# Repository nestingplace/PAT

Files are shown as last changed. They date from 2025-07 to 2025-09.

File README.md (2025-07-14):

# PAT — Portable Audio Tool (Sampler/Sequencer/Synth)

<p align="center">
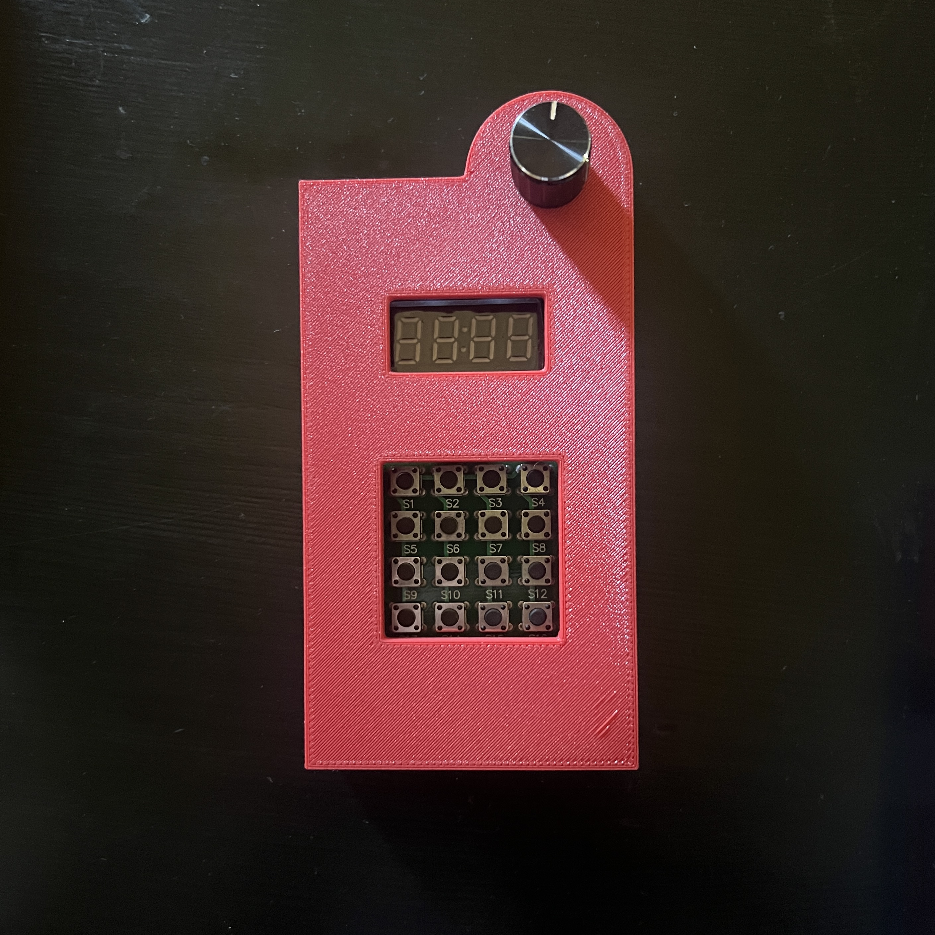
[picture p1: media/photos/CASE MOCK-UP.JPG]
Case Mock-Up
  
</p>

A standalone, hardware-based sampler and digital synthesizer built around the RP2040 microcontroller. Designed for real-time musical performance and DIY audio exploration. Developed in MicroPython, with integrated analog effects and a full sequencer UI.

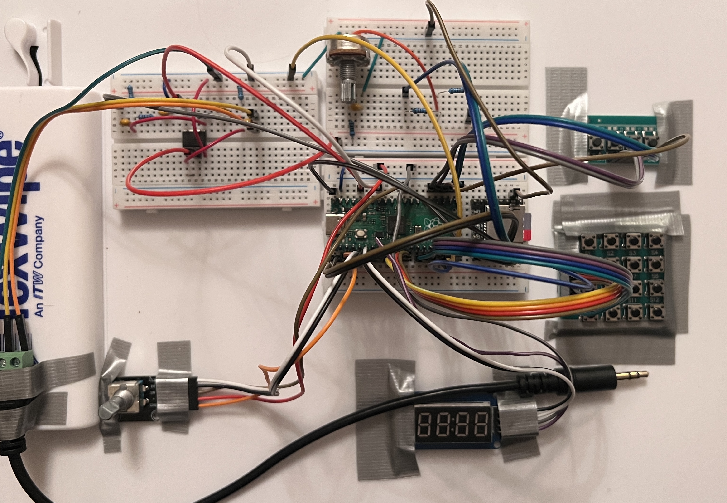
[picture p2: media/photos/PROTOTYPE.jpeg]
PAT Breadboard


# Features

- Sample playback with 16 step ( 8x2 ) grid sequencer and visualizer ( DFR0229 )
- Digital synth engine ( DDS-based ) with triangle, saw, square, and sine waveforms
- PWM audio output with ( RC ) bandpass filtering
- Encoder-based control of waveform, envelope, and FX parameters
- Transistor-based analog tremolo ( LFO modulated )
- Mode-switchable SYNTH / SAMPLE engine with combined audio out ( active summing )
- Midi & sync output support via 3.5mm TRS ( type-B )
- Open-source firmware, hardware, and enclosure design
- 2 keypads, 20 buttons ( 16 for note/sample playback, 4 for UI )
- Encoder knob for menu navigation and SYNTH control modes
- 7-segment display with fully populated menu and visual queues
- 3D printed case, fully assembled with snap-fit standoffs

# Folder Overview

- `/firmware`: MICROPYTHON CODEBASE
- `/hardware`: CIRCUIT DIAGRAMS, 3D MODELS, ETC.
- `/media`: PHOTOS & VIDEOS
- `/docs`: PRINTABLE DATASHEETS

# Technical Highlights

- Real-time waveform synthesis via PWM and timer interrupts
- Synth control modes: CUTOFF, FADE-IN, ASDR ENV, FILTER SWEEP, FILTER MOD, and PITCH BEND
- Modular state machine controlling input, output, and mode logic
- Minimal latency sampling engine using UART protocol and <asyncio>
- Playback speeds of 60-140 bpm ( 16th notes, max of 560 steps per minute )
- Threaded synth logic for DUAL MODE, SYNTH and SEQUENCER combined operation
- Permanent storage of program configuration and sequencer patterns
- Import custom sample banks via micro SD card ( MP3 and WAV )
- Fully documented hardware stack for easy replication

# Demo

SYNC W/ KORG VOLCA

SYNC : KORG VOLCA (https://youtu.be/XOAL12_DOX0)

SYNTH CONTROL 1

SYNTH CONTROL 1 (https://www.youtube.com/shorts/shXTFsdpJ9k)

SYNTH CONTROL 2

SYNTH CONTORL 2 (https://www.youtube.com/shorts/4oDAa_RGoyw)

# Work in Progress

- SYNTH melody sequencing, by step-based assignment of both rhythmic and melodic values
- Communication of SYNTH sequence values (beat & note) via MIDI-OUT signal
- Analog FX builds : DISTORTION, REVERB, DELAY

---

# Creator

Ken Hill – Embedded Engineer , [somuchfunwithwords@gmail.com](mailto:somuchfunwithwords@gmail.com)

[View my portfolio](https://drive.google.com/drive/folders/13Q4Rg4acVu6Zbi14zaWPo625oAb1vngg?usp=drive_link) | [LinkedIn](https://www.linkedin.com/in/ken-hill-5a03b9225)

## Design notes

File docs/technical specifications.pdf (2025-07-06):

STORAGE
ON-BOARD
DRIVERS | 40 KB
BUILD | 8.0 KB
TOTAL | 2 MB

SDHC MICRO SD CARD
64 x MP3 | ≈ 8 MB
TOTAL | 32 GB

POWER BUDGET
RPi PICO | - 100mA
TM1637 DISPLAY | - 80mA
4X4 KEYPAD | - 5mA
KY040 ENCODER | - 15mA
AUDIO MODULE | - 300mA
TP2399 DELAY | - 30mA
LM358 OP-AMP | - 20mA
PT2399 DELAY | - 30mA
LI-PO BATTERY | + 10000mAh + 5000mAh + 2500mAh
TOTAL | 10000mAh / 525mA _________ 19.05h
| 5000mAh / 525mA _________ 9.53h
| 2500mAh / 525mA _________ 4.76h

# technical specifications

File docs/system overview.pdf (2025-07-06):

### I. HARDWARE

CURRENT HARDWARE

RPi Pico Main microcontroller (PWM + GPIO management) DFR0229 MP3 audio playback module (sampler)
TM1637 Display 4-digit 7-segment for menu and sequence UI KY040 Encoder Navigation knob with rotation and button
4x4 Keypad Primary input matrix (samples, controls)
3.5mm TRS Port 1 Main audio output (stereo or mono blend) 3.5mm TRS Port 2 MIDI OUT or SYNC OUT toggleable
LP Filter Bandpass filter for PWM synth (23.4 Hz–7.2 kHz) LM358 Op-amp for signal buffering and blending

### II. SOFTWARE ARCHITECTURE

LANGUAGE & OPERATING SYSTEM

MicroPython (Async + Threading)

Event-driven architecture, with I/O polling via coroutines and background threading for concurrent synth playback

### III. PROGRAM LOGIC

PROGRAMS AND DATA STRUCTURES

### 4 user-selectable "Programs" (P1–P4)

Each program saves to its own .json config file

Program data includes:

BPM
Waveform
Synth Control Mode
Sequence Pattern
MIDI/SYNC Mode

Samples are stored and triggered according to DFR0229 folder/file scheme (folder = program number, file = keypad index)

### IV. FUNCTIONAL MODES

### 1. SAMPLER MODE

# system overview

– Direct triggering of samples via keypad – Uses DFPlayer async protocol – Supports 16 samples (mapped 1–16 on 4x4 matrix) – Output is stereo or mono (merged via analog blend)

2. SEQUENCER MODE – 16-step pattern sequencer with live visual display (TM1637) – Encoder selects step; keypad assigns sample

Control buttons: - START/STOP

- DELETE STEP
- CLEAR PATTERN
- TOGGLE DUAL MODE –

– Pattern auto-saves and auto-loads per program
BPM affects: - Sample timing
- MIDI Clock or SYNC pulse (selected via CONFIGURE) –

– Sequence runs asynchronously, with idle visual feedback when stopped

3. SYNTHESIZER MODE – Monophonic DDS-style digital synth via PWM (GPIO15) – Waveforms: SIN, TRI, SAW, SQR (generated via 256-point lookup tables) – Keypad maps to C3–C4 notes

Encoder adjusts real-time modulation target: - DISABLED

- CUTOFF
- ASDR
- FILTER MOD
- FILTER SWEEP
- PITCH BEND

–

– Synth playback uses background threading – Static bandpass filter applied post-PWM

– Output merged via op-amp circuit with DFR0229 stream

### 4. CONFIGURATION MENU

Accessible per program, with options: – BPM: Set tempo (60–140 BPM) – WAVE: Select default waveform for synth – CTRL: Assign encoder's control mode in synth

MIDI / SYNC: - Mutually exclusive
- Determines output type on TRS Port 2 – V. I/O & DISPLAY INTERFACE
Input | Description
Encoder | Navigation + value editing

Encoder SW | Select / Back
Keypad | Note/sample trigger & sequence edit
Output | Description
TM1637 Display | 4-char mode/status & sequence grid
TRS Port 1 | Stereo or mono audio out
TRS Port 2 | MIDI or SYNC signal out

### VI. ADVANCED FEATURES

Live pattern recording:
Sample assignment while sequence runs

Async + threading:
Asyncio for playback/scheduler loop
Thread for continuous synth tone generation

Dual mode:
Allows for concurrent synth/sequencer operaiton

Power system:
USB-C charging via TP4056
Rechargeable Li-Po battery

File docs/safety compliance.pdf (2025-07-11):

Document Version: 1.0
Project: Sampler / Sequencer / Synthesizer Date: [07/11/2025]

## Electrical Safety

Device operates at low voltages (≤5V DC).
Supply voltages:
Raspberry Pi Pico: 1.8–5.5V (VSYS), 3.3V logic DFPlayer Mini: 3.2–5V supply, 3.3–5V logic Always use a regulated, fused 5V supply.
Protect against reverse polarity and short circuits.

## Thermal Safety

No significant heat generation expected.
Ambient operating temperature: 0–50°C recommended. Provide basic airflow to avoid heat buildup.

## Mechanical Safety

Enclosure must have smooth edges, secure mounting. Use PCB standoffs; avoid stressing connectors. External ports (TRS, power) must be strain-relieved.

## EMI & ESD

Ground metal parts to reduce ESD risk.
Keep digital signal lines away from audio paths.
Use shielded cables where possible.

## MIDI & SYNC Output

MIDI OUT conforms to MIDI 1.0 electrical spec (31250 baud, 5V). TRS Type B wiring:
Tip → UART TX via 220Ω
Ring → GND
Sleeve → GND
SYNC OUT: 0–5V square wave, 16 pulses per quarter note.

## Software Safety

Debounce all mechanical inputs.
Ensure all GPIOs are set to known states at power-on. Provide “STOP” mode to silence audio and reset safely.

## Compliance Guidance

This project is DIY and not certified; however, design aligns with: CE / FCC Part 15 Class B (EMC)
RoHS (lead-free solder, compliant components)
WEEE (recyclable materials recommended)

# safety compliance

## Component Notes

Component | Notes
Raspberry Pi Pico | CE, FCC, RoHS certified development board.
DFPlayer Mini (DFR0229) Ensure clean 3.2–5V rail for noise-free audio.
TM1637 Display | 3.3–5V tolerant.
KY-040 Encoder | Mechanical bounce — debounce required.
Custom Analog Circuits Keep within safe voltage/current limits.

## Recommended Protections

Series resistors (220–1kΩ) on all GPIO outputs.
100nF ceramic decoupling caps on supply rails.
Fuse on main power input (500mA–1A fast-blow recommended).

For internal and educational use only. Not an official certified document.

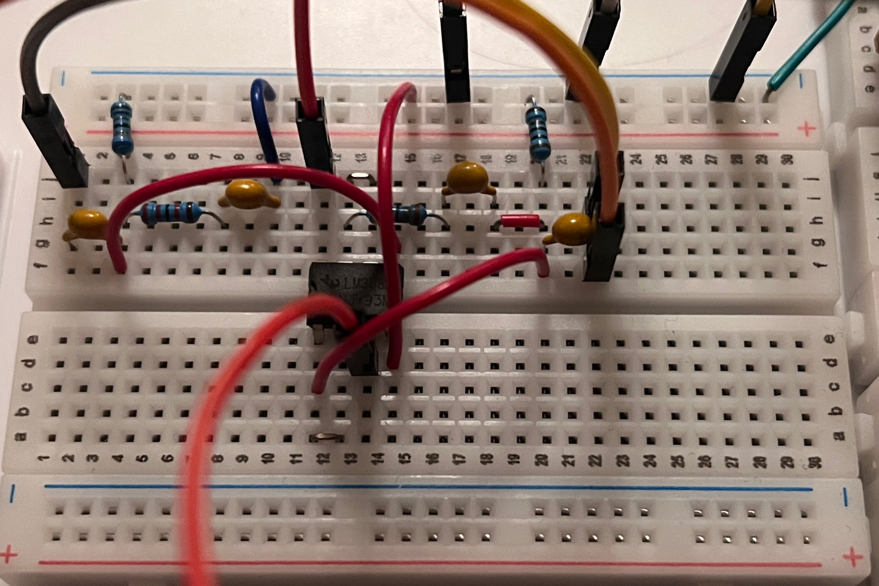
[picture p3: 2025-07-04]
media/photos/BP FILTER + AMPLIFIER.jpeg

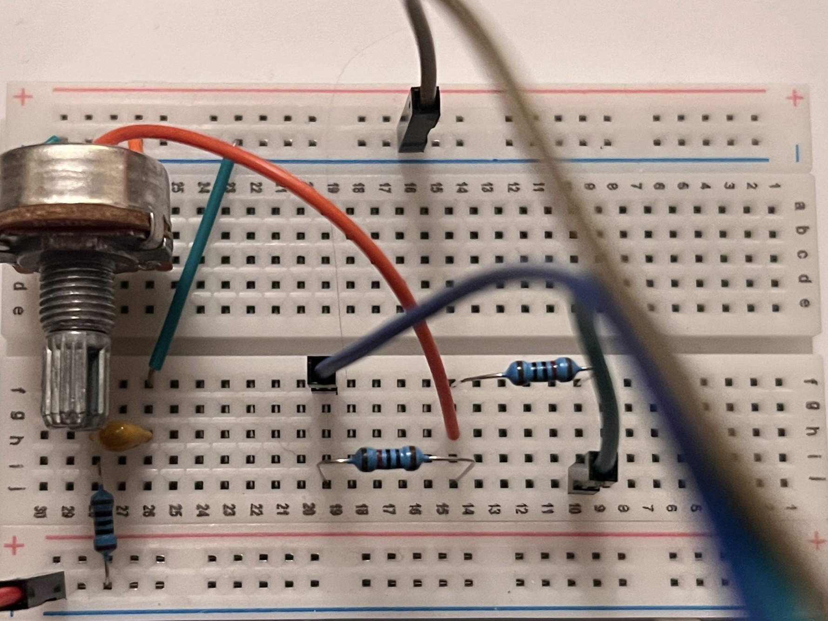
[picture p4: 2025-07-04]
media/photos/LP FILTER.jpeg

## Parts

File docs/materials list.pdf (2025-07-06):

BILL OF MATERIALS
RPi PICO BOARD | RPi PICO $1.95 OR RPi PICO 2 $5.41
TM1637 DISPLAY | $0.94-2.86
4X4 KEYPAD | $0.66-3.14
KY040 ENCODER | $1.53-4.68
POWER SUPPLY | 5 VDC MINI-PLUG AC ADAPTER $3.89 3.7V RECHARGABLE LI-PO BATTERY 10000mAh $9.47 OR 3.7V RECHARGABLE LI-PO BATTERY 5000mAh $7.49 OR 3.7V RECHARGABLE LI-PO BATTERY 2500mAh $8.16 + LITHIUM BATTERY CHARGING MODULE $0.99
AUDIO MODULE | RPi PICO AUDIO BOARD $4.91 DFR0299 $1.33 + PJ-320D 3.5MM TRS PANEL-MOUNT JACK $0.12 LM358P DUAL OP-AMP $2.35 B100K POTENTIOMETER $1.03
TOTAL MIN | $26.92
TOTAL MAX | $40.03

# materials list

OTHER COMPONENTS
5-WAY SWITCH | R16 ROTARY BAND SWITCH [SP5T] $2.89
AUDIO-FX MODULE | PT2399 BOARD $2.61-5.36
3.5MM TERMINAL | 3-PIN MALE AUDIO/VIDEO PLUG $2.61
4X1 KEYPAD | 4-PIN INPUT ARRAY $0.87
MICRO SD CARD | 32GB SDHC MICRO SD CARD $3.05-6.63

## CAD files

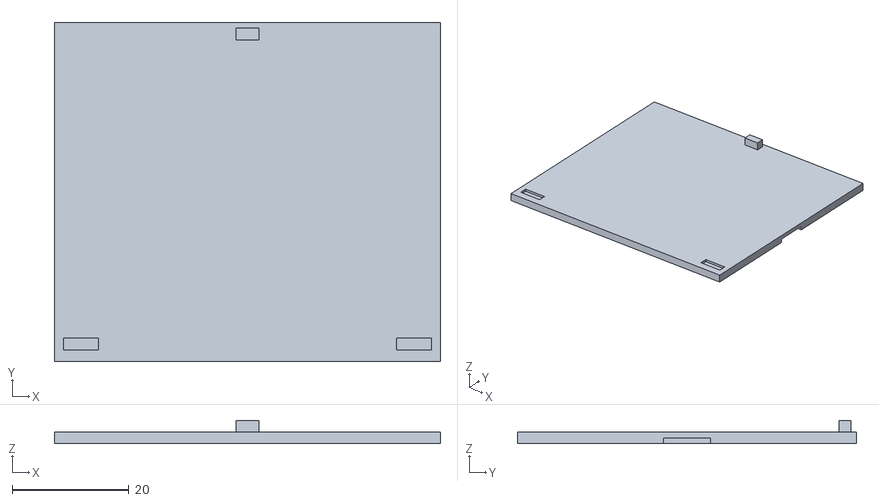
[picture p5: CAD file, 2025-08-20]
hardware/case design/STL/sequencer_case_INSERT_v1.1.stl
66.0 x 58.0 x 4.00

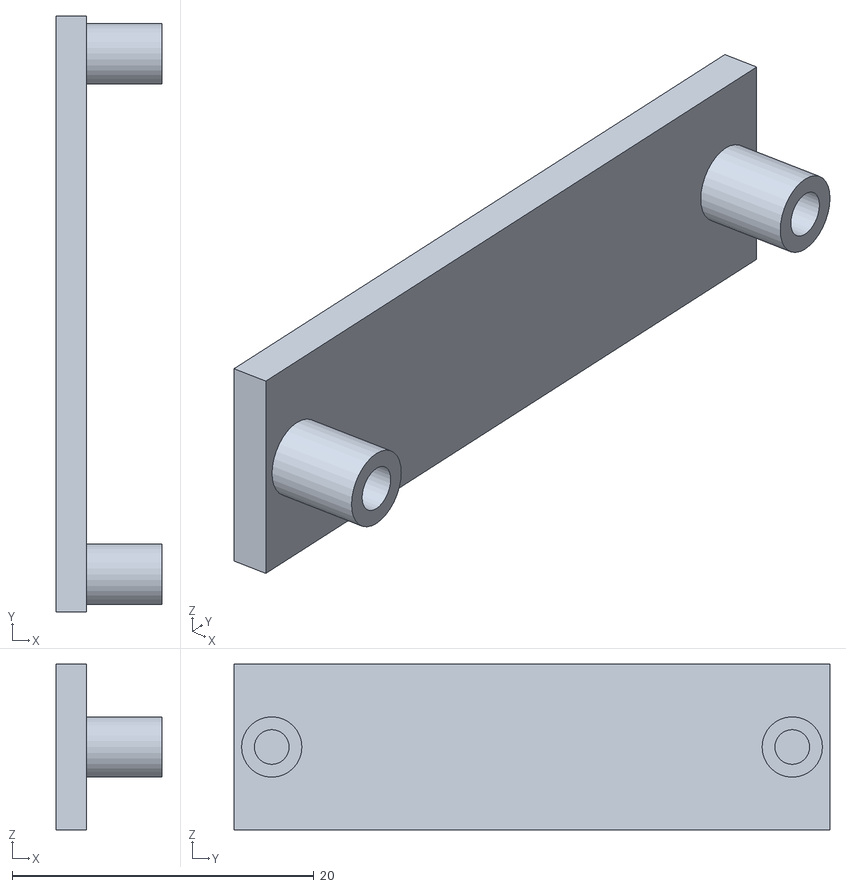
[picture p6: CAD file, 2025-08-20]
hardware/case design/STL/sequencer_case_AUDIOBOARDCLIP_v1.0.stl
7.00 x 39.5 x 11.0

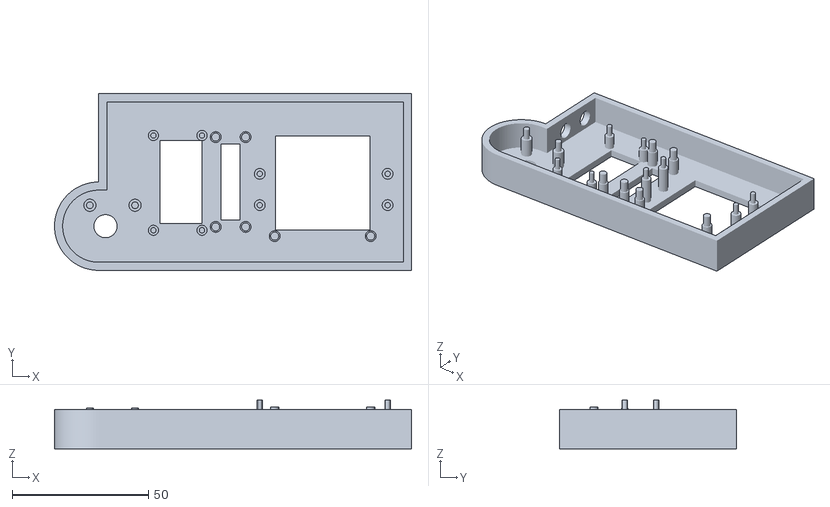
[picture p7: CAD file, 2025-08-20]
hardware/case design/STL/sequencer_case_FRONT_v2.3.stl
131.2 x 65.0 x 18.0

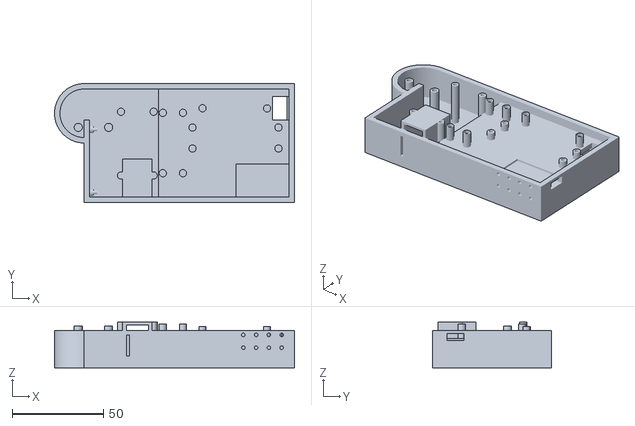
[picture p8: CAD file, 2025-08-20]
hardware/case design/STL/sequencer_case_BACK_v2.6.stl
131.2 x 65.0 x 25.0

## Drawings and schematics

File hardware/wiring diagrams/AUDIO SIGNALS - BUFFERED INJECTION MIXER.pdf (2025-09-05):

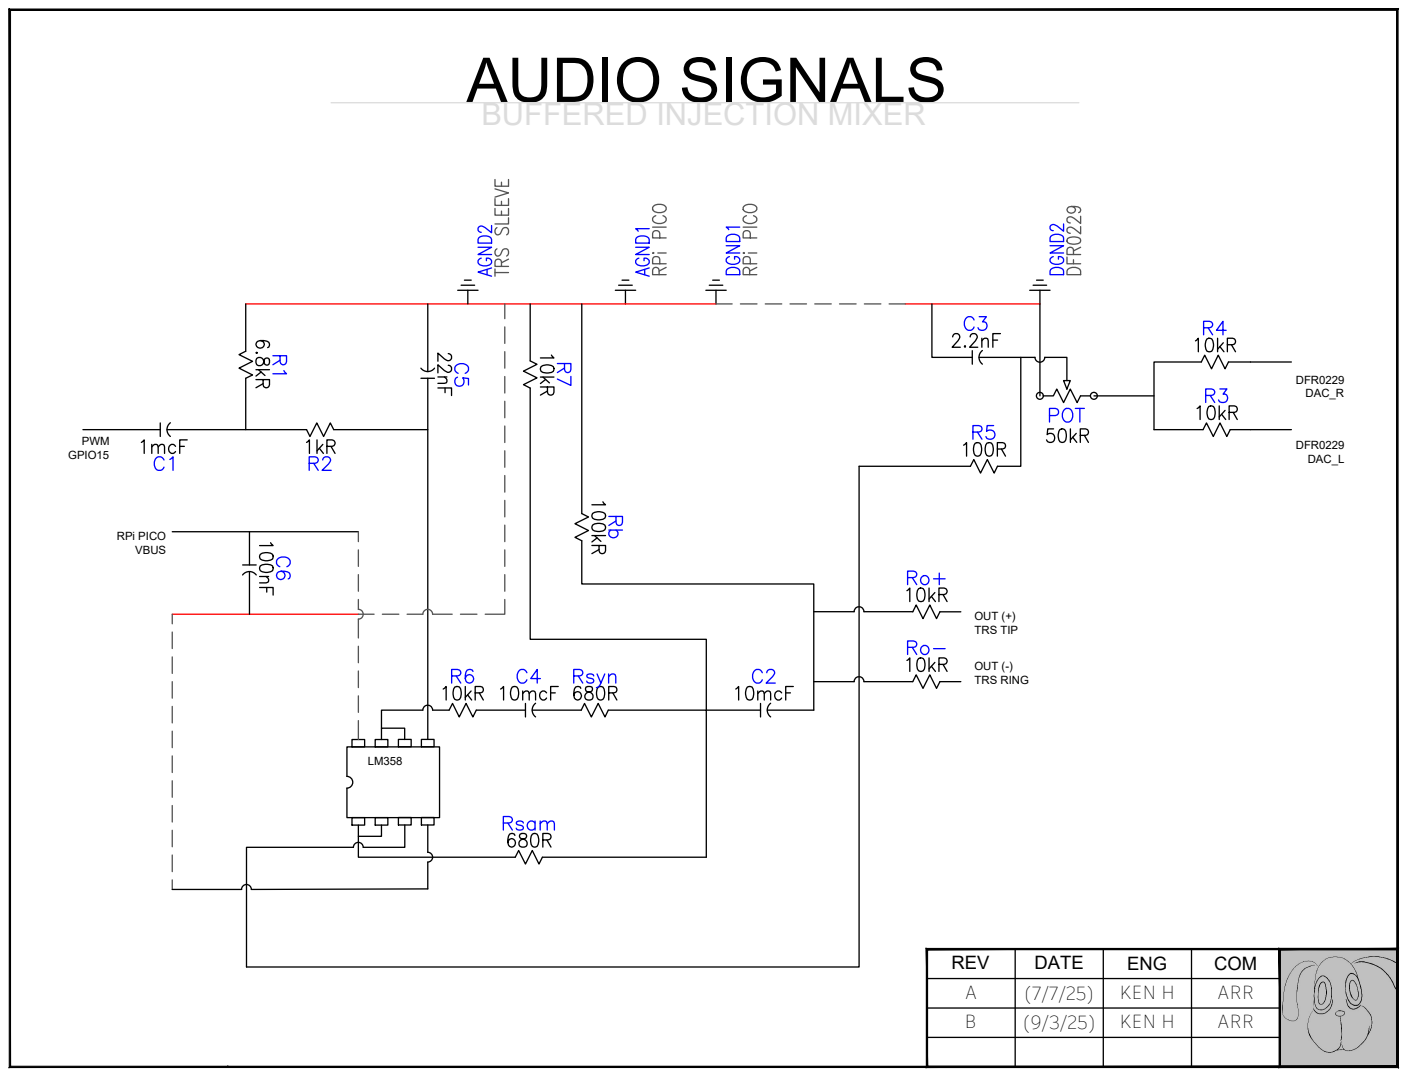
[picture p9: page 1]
AUDIO SIGNALS BUFFERED INJECTION MIXER; REV; DATE; ENG; COM A; KEN H; ARR; DFR0229 DAC_R DFR0229 DAC_L OUT (+) TRS TIP OUT (-) TRS RING RPi PICO VBUS; LM358 PWM GPIO15

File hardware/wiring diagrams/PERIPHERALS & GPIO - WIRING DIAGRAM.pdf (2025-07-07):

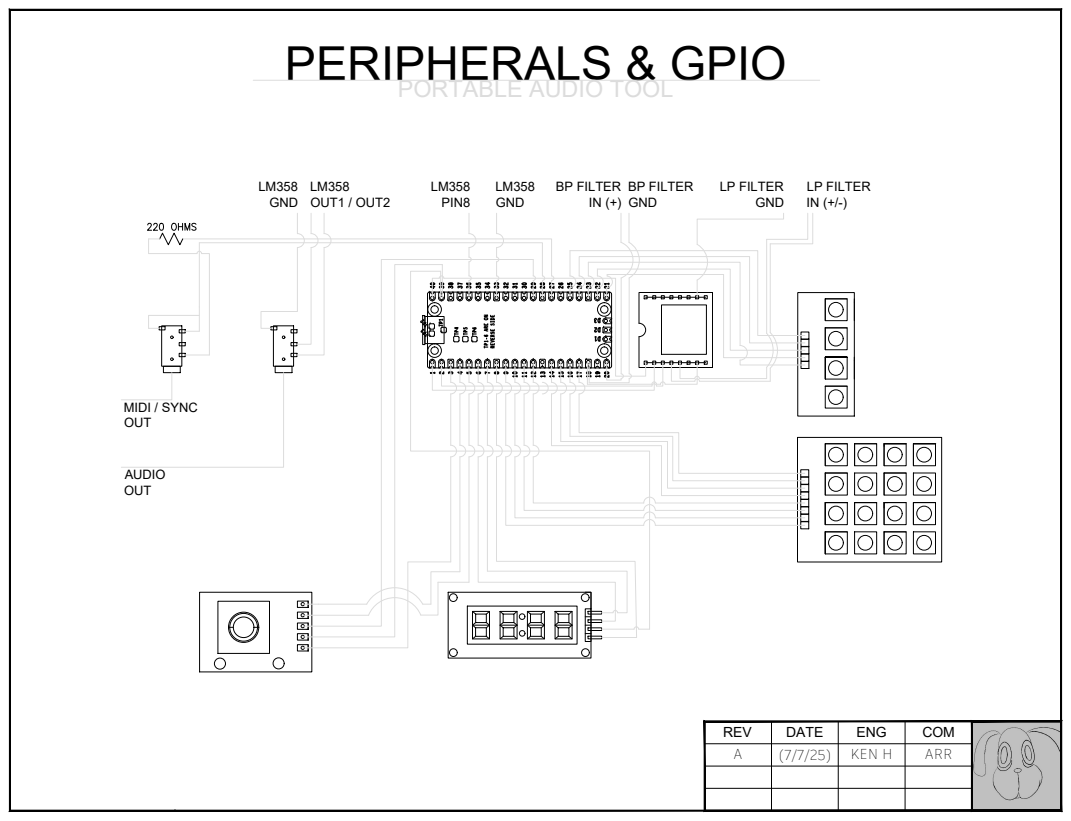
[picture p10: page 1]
LM358 PIN8; LM358 GND; BP FILTER IN (+) BP FILTER GND MIDI / SYNC OUT AUDIO OUT; LP FILTER GND; LP FILTER IN (+/-) LM358 GND LM358 OUT1 / OUT2 PERIPHERALS & GPIO PORTABLE AUDIO TOOL; REV; DATE; ENG; COM A; KEN H; ARR

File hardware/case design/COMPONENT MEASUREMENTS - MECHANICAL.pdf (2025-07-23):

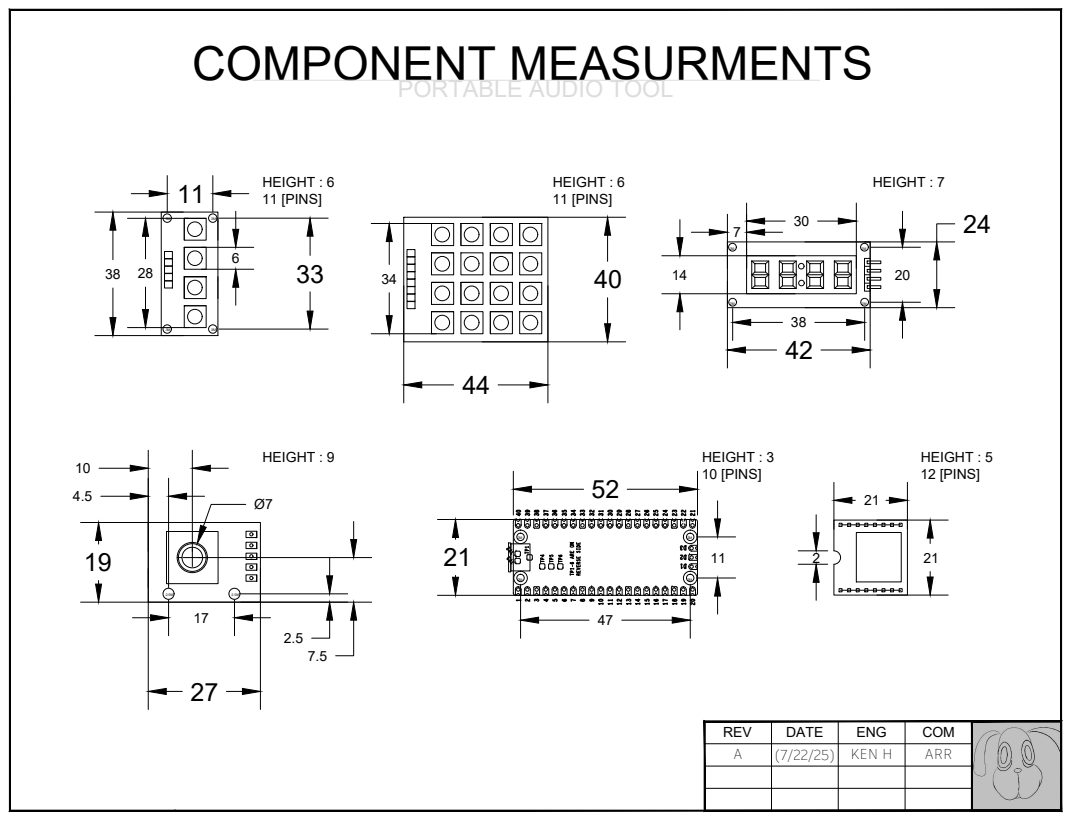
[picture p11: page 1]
REV; DATE; ENG; COM A; KEN H; ARR COMPONENT MEASURMENTS 3M; HEIGHT : 6 11 [PINS]; 40 HEIGHT : 6 11 [PINS]; HEIGHT : 7 2M; 20 HEIGHT : 9; HEIGHT : 3 10 [PINS]; HEIGHT : 5 12 [PINS] 27 19; 21 PORTABLE AUDIO TOOL

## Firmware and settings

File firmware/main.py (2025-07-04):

# STANDARD LIBRARIES
import uasyncio as asyncio
import time
import ujson
from machine import Pin, UART

# PERIPHERAL DRIVERS
from dfplayer import DFPlayer
from keypad import Keypad
from navpad import Navpad
from encoder import Encoder
from tm1637 import TM1637

# CUSTOM OBJECTS
from sequencer import Sequencer
from tremolo import TremoloController
from synthesizer import Synthesizer

# DRIVER INITIALIZATION
df = DFPlayer(uart_id=0, tx_pin_id=0, rx_pin_id=1)
df.volume(100)

midi_uart = UART(1, baudrate=31250, tx=Pin(20))

tm_display = TM1637(clk=Pin(5), dio=Pin(4))

A_ROWS = 4
A_COLS = 4
A_ROW_PINS = [13, 12, 11, 10]
A_COLUMN_PINS = [9, 8, 7, 6]
A_KEYMAP = ['1', '2', '3', 'A',
          '5', '6', '7', 'B',
          '9', '10', '11', 'C',
          '13', '14', '15', 'D']

keypad = Keypad(A_KEYMAP, A_ROW_PINS, A_COLUMN_PINS, A_ROWS, A_COLS)
keypad.set_debounce_time(200)

B_PINS = [19, 18, 17, 16]
B_KEYMAP = ['17', '18', '19', 'E']

navpad = Navpad(B_KEYMAP, B_PINS)

tremolo = TremoloController(pin_num=19, bpm=80, display=tm_display)

encoder = Encoder(2, 3, 22)

programs = ["P1", "P2", "P3", "P4"]
current_program_index = 0

# BOOT SCREEN

tm_display.scroll("Hello Hello Hello Hello")

# HANDLE PROGRAM DATA [JSON]
from program_io import load_program, save_program

def load_program(program_name):  # Legacy definition replaced
    folder_number = int(program_name[1:])
    try:
        with open(f"{program_name}.json", "r") as f:
            data = ujson.load(f)
    except:
        data = {}
    return {
        "program": program_name,
        "folder": folder_number,
        "bank":data.get("bank",1),
        "bpm": data.get("bpm", 80),
        "waveform": data.get("waveform", "SIN"),
        "control": data.get("control", "DISABLED"),
        "control_value": data.get("control_value", 0),
        "sequence": data.get("sequence", [None] * 16),
        "midi": data.get("midi", False),
        "sync": data.get("sync", False)
    }

def save_program(program_data):
    name = program_data.get("program")
    if not name:
        folder = program_data.get("folder", 1)
        name = f"P{folder}"
        program_data["program"] = name
    with open(f"{name}.json", "w") as f:
        ujson.dump(program_data, f)
        
def display_program(name):
    tm_display.show('    ')
    tm_display.show(name)

def change_bank(program_data, toggle):
    bank = program_data.get("bank", 1)
    if toggle:
        bank = 1 if bank >= 4 else bank + 1
    else:
        bank = 4 if bank <= 1 else bank - 1
    program_data["bank"] = bank
    save_program(program_data)
    
# DISPLAY MAP

def display_mode(mode):
    tm_display.show('    ')
    
    # PROGRAM SUB-MENU
    if mode == "SELECT":
        tm_display.show("SEL")
    elif mode == "SAMPLE":
        tm_display.show("SAMP")
    elif mode == "SYNTH":
        tm_display.show("SYNT")
    elif mode == "SEQ":
        tm_display.show("SEQ")
    elif mode == "CONFIGURE":
    
    # CONFIGURATION MENU
        tm_display.show("CNFG")
    elif mode == "BACK":
        tm_display.show("BACK")
    elif mode == "BPM":
        tm_display.show("BPM")
    elif mode == "WAVE":
    
    # WAVEFORMS
        tm_display.show("WAVE")
    elif mode == "SIN":
        tm_display.show("SIN")
    elif mode == "TRI":
        tm_display.show("TRI")
    elif mode == "SAW":
        tm_display.show("SAW")
    elif mode == "SQR":
        tm_display.show("SQR")
    
    # CONTROL MODES
    elif mode == "CTRL":
        tm_display.show("CTRL")
    elif mode == "DISABLED":
        tm_display.show("DSBL")
    elif mode == "CUTOFF":
        tm_display.show("CUT")
    elif mode == "ASDR":
        tm_display.show("FIN")
    elif mode == "ASDR_WAVE":
        tm_display.show("ASDR")
    elif mode == "FILTER MOD":
        tm_display.show("FMOD")
    elif mode == "FILTER SWEEP":
        tm_display.show("FSWP")
    elif mode == "PITCH BEND":
        tm_display.show("PBND")
    elif mode == "ON":
        tm_display.show("ON")
    elif mode == "OFF":
        tm_display.show("OFF")
        
    # MIDI / SYNC
    elif mode == "MIDI":
        tm_display.show("MIDI")
    elif mode == "MIDI ON":
        tm_display.show("ON")
    elif mode == "MIDI OFF":
        tm_display.show("OFF")
    elif mode == "SYNC":
        tm_display.show("SYNC")
    elif mode == "SYNC ON":
        tm_display.show("ON")
    elif mode == "SYNC OFF":
        tm_display.show("OFF")

running_program = False
sequencer_global = None  # GLOBAL SEQUENCER REFERENCE

# SYNTH MODE [PWM/THREADING]

async def synth_mode(program_data):
    display_mode("SYNTH")
    synth = Synthesizer(pwm_pin=15, program_data=program_data)

    note_map = {
        '1': 261.63, '2': 293.66, '3': 329.63, 'A': 349.23,
        '4': 392.00, '5': 440.00, '6': 493.88, 'B': 523.25,
        '7': 554.37, '8': 587.33, '9': 622.25, 'C': 659.25,
        '10': 698.46, '11': 739.99, '12': 783.99, 'D': 830.61
    }

    current_key = None
    while True:
        key = keypad.get_key()
        nav = navpad.get_key()

        if nav:
            if nav == 'E':
                synth.octave_up()
            elif nav == '19':
                synth.octave_down()
            # elif nav == '18':
            # elif nav == '17':

        if key in note_map:
            if key != current_key:
                    synth.stop_note()
                    current_key = key
                    synth.start_note(note_map[key])
        else:
            # NO KEY DETECTED, CHECKS FOR RELEASE OF MOST RECENT KEY
            if current_key and not keypad.is_pressed(current_key):
                synth.stop_note()
                current_key = None
       
        direction = encoder.get_direction()
        if direction:
            synth.update_control(direction)

        if encoder.get_button_press():
            synth.stop_note()
            return

        await asyncio.sleep_ms(10)

# SAMPLE MODE [DFPLAYER]

async def sample_mode(folder, program_data):
    global running_program
    running_program = True
    
    SAMPLE_KEYMAP = {
    '1': 1,  '2': 2,  '3': 3,  'A': 4,
    '5': 5,  '6': 6,  '7': 7,  'B': 8,
    '9': 9,  '10': 10, '11': 11, 'C': 12,
    '13': 13, '14': 14, '15': 15, 'D': 16
    }
    
    tm_display.scroll(f"B{program_data['bank']}")
    display_mode("SAMPLE")
    
    while running_program:
        
        key = keypad.get_key()
        nav = navpad.get_key()

        # KEYPAD
        if key in SAMPLE_KEYMAP:
            key_num = SAMPLE_KEYMAP[key]
            sample_offset = (program_data["bank"] - 1) * 16
            sample = key_num + sample_offset
            await df.play(folder, sample)
            
            # DEBUG
            print(f"Key {key} → Sample {sample}")

        # NAVPAD
        if nav:
            if nav == 'E':
                change_bank(program_data, toggle=True)
                tm_display.scroll(f"B{program_data['bank']}")
                display_mode("SAMPLE")
            elif nav == '19':
                change_bank(program_data, toggle=False)
                tm_display.scroll(f"B{program_data['bank']}")
                display_mode("SAMPLE")
                
            # elif nav == '18':
            # elif nav == '17':

        if encoder.get_button_press():
            running_program = False

# PROGRAM SUB-MENU

async def launch_program(program_index):
    global running_program, sequencer_global
    folder = program_index + 1
    program_data = load_program(programs[program_index])
    program_data["folder"] = folder
    submenu_index = 0
    submenu_options = ["SELECT", "SAMPLE", "SYNTH", "SEQ", "CONFIGURE"]
    last_time = time.ticks_ms()
    last_dir = 0

    if "bpm" not in program_data:
        program_data["bpm"] = 80
    if "bank" not in program_data:
        program_data["bank"] = 1

    while True:
        display_mode(submenu_options[submenu_index])
        direction = encoder.get_direction()
        now = time.ticks_ms()

        if direction != 0:
            if direction != last_dir or time.ticks_diff(now, last_time) > 200:
                submenu_index = (submenu_index + direction) % len(submenu_options)
                display_mode(submenu_options[submenu_index])
                last_dir = direction
                last_time = now

        if encoder.get_button_press():
            mode = submenu_options[submenu_index]

            if mode == "SELECT":
                return

            elif mode == "SAMPLE":
                await sample_mode(folder, program_data)

            elif mode == "SYNTH":
                await synth_mode(program_data)

            elif mode == "SEQ":
                display_mode("SEQ")
                tm_display.show('    ')
                sequencer = Sequencer(encoder, tm_display, df, keypad, navpad, midi_uart, program_data)
                sequencer.set_folder(folder)
                sequencer.mode = "SEQ"
                sequencer.update_display()
                sequencer_global = sequencer
            
                keypad._prev_key = None
                
                while True:
                    direction = encoder.get_direction()
                    now = time.ticks_ms()

                    # BLOCK BLINKING CURSOR : DUAL MODE
                    if not sequencer.dual_mode and direction != 0:
                        if direction != last_dir or time.ticks_diff(now, last_time) > 200:
                            sequencer.current_step = (sequencer.current_step + direction) % 16
                            sequencer.update_display()
                            sequencer.blink_state = True
                            sequencer.last_blink_time = now
                            last_dir = direction
                            last_time = now

                    key_event = keypad.get_key()
                    nav_event = navpad.get_key()

                    if key_event:
                        
                        if sequencer.dual_mode and not sequencer.running:
                            # KEY HANDLING : DUAL MODE [IDLE]
                            sequencer.current_key = key_event
                            await sequencer.handle_dual_mode_inputs()

                        elif not sequencer.dual_mode :
                            await sequencer.assign_sample(key_event)
                            
                    elif nav_event:
                        
                        if nav_event == 'E':
                            
                            if not sequencer.running:
                                await sequencer.run_sequence(None)
                            else:
                                sequencer.stop_sequence()
                                
                        elif nav_event == '19':
                            sequencer.clear_entire_pattern()
                            
                        elif nav_event == '18':
                            sequencer.clear_step()
                            
                        elif nav_event == '17':
                            if time.ticks_diff(time.ticks_ms(), sequencer.last_toggle) > 250:
                                await sequencer.toggle_dual_mode()

                    # CONSTANT SYNTH SCAN : DUAL MODE [IDLE]
                    if sequencer.dual_mode and not sequencer.running and not key_event:
                        await sequencer.handle_dual_mode_inputs()

                    if encoder.get_button_press():
                        sequencer.stop_sequence()
                        return

                    await asyncio.sleep_ms(1)
                    
                    # BLINKING CURSOR : SEQUENCE EDIT MODE
                    sequencer.update_idle_visual()

            elif mode == "CONFIGURE":
                await open_configure_menu(program_data)

        await asyncio.sleep_ms(1)

# BOOT CONDITIONS

# tm_display.scroll("Hello Hello Hello Hello")
# time.sleep(0.5)

display_program(programs[current_program_index])

last_direction = 0
last_time = 0

# PROGRAM CONFIGURATION MENU

async def open_configure_menu(program_data):
    config_options = ["BACK", "BPM", "WAVE", "CTRL", "MIDI", "SYNC"]
    config_index = 0
    last_dir = 0
    last_time = time.ticks_ms()

    display_mode(config_options[config_index])

    while True:
        display_mode(config_options[config_index])
        direction = encoder.get_direction()
        now = time.ticks_ms()
        if direction != 0:
            if direction != last_dir or time.ticks_diff(now, last_time) > 200:
                config_index = (config_index + direction) % len(config_options)
                last_dir = direction
                last_time = now
                display_mode(config_options[config_index])

        if encoder.get_button_press():
            selected = config_options[config_index]
            if selected == "BACK":
                return

            elif selected == "BPM":
                bpm = program_data.get("bpm", 80)
                tm_display.number(bpm)
                while True:
                    direction = encoder.get_direction()
                    now = time.ticks_ms()
                    if direction != 0:
                        if direction != last_dir or time.ticks_diff(now, last_time) > 200:
                            bpm = max(60, min(140, bpm + direction))
                            tm_display.number(bpm)
                            last_dir = direction
                            last_time = now
                    if encoder.get_button_press():
                        program_data["bpm"] = bpm
                        save_program(program_data)
                        break
                    time.sleep_ms(10)

            elif selected == "WAVE":
                waveforms = ["SIN", "TRI", "SAW", "SQR"]
                current_index = waveforms.index(program_data.get("waveform", "SIN"))
                display_mode(waveforms[current_index])
                while True:
                    direction = encoder.get_direction()
                    now = time.ticks_ms()
                    if direction != 0:
                        if direction != last_dir or time.ticks_diff(now, last_time) > 200:
                            current_index = (current_index + direction) % len(waveforms)
                            display_mode(waveforms[current_index])
                            last_dir = direction
                            last_time = now
                    if encoder.get_button_press():
                        program_data["waveform"] = waveforms[current_index]
                        save_program(program_data)
                        break
                    time.sleep_ms(10)

            elif selected == "CTRL":
                ctrl_options = ["DISABLED", "CUTOFF", "ASDR","ASDR_WAVE", "FILTER MOD", "FILTER SWEEP", "PITCH BEND"]
                current_ctrl = program_data.get("control", "DISABLED")
                if current_ctrl not in ctrl_options:
                    current_ctrl = "DISABLED"
                current_index = ctrl_options.index(current_ctrl)
                display_mode(ctrl_options[current_index])
                while True:
                    direction = encoder.get_direction()
                    now = time.ticks_ms()
                    if direction != 0:
                        if direction != last_dir or time.ticks_diff(now, last_time) > 200:
                            current_index = (current_index + direction) % len(ctrl_options)
                            display_mode(ctrl_options[current_index])
                            last_dir = direction
                            last_time = now
                    if encoder.get_button_press():
                        selected_ctrl = ctrl_options[current_index]
                        program_data["control"] = selected_ctrl
                        
                        if selected_ctrl == "DISABLED":
                            program_data["control_value"] = 0
                        elif selected_ctrl == "CUTOFF":
                            program_data["control_value"] = 32767
                        elif selected_ctrl == "ASDR":
                            program_data["control_value"] = 10000
                        elif selected_ctrl == "ASDR_WAVE":
                            program_data["control_value"] = 32767
                        elif selected_ctrl == "FILTER MOD":
                            program_data["control_value"] = 16384
                        elif selected_ctrl == "FILTER SWEEP":
                            program_data["control_value"] = 1000
                        elif selected_ctrl == "PITCH BEND":
                            program_data["control_value"] = 32767

                        display_mode("ON")
                        time.sleep(1)
                        save_program(program_data)
                        break
                    time.sleep_ms(10)

            elif selected == "MIDI":
                program_data["midi"] = not program_data.get("midi", False)
                program_data["sync"] = False
                display_mode("MIDI ON" if program_data["midi"] else "MIDI OFF")
                save_program(program_data)
                time.sleep(1)
                display_mode(config_options[config_index])

            elif selected == "SYNC":
                program_data["sync"] = not program_data.get("sync", False)
                program_data["midi"] = False
                display_mode("SYNC ON" if program_data["sync"] else "SYNC OFF")
                save_program(program_data)
                time.sleep(1)
                display_mode(config_options[config_index])

# OPERATIONAL LOGIC

async def main_loop():
    global last_direction, last_time, running_program, current_program_index, sequencer_global
    while True:
        if not running_program:
            direction = encoder.get_direction()
            current_time = time.ticks_ms()
            if direction != 0:
                if direction != last_direction or time.ticks_diff(current_time, last_time) > 200:
                    current_program_index = (current_program_index + direction) % len(programs)
                    display_program(programs[current_program_index])
                    last_direction = direction
                    last_time = current_time

            if encoder.get_button_press():
                await launch_program(current_program_index)
                display_program(programs[current_program_index])

        await asyncio.sleep_ms(20)

asyncio.run(main_loop())

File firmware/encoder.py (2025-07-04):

import machine
import time

class Encoder:
    def __init__(self, clk_pin, dt_pin, sw_pin):
        self.clk = machine.Pin(clk_pin, machine.Pin.IN, machine.Pin.PULL_UP)
        self.dt = machine.Pin(dt_pin, machine.Pin.IN, machine.Pin.PULL_UP)
        self.sw = machine.Pin(sw_pin, machine.Pin.IN, machine.Pin.PULL_UP)

        self.last_state = (self.clk.value() << 1) | self.dt.value()
        self.last_time = time.ticks_ms()

    def get_direction(self):
        state = (self.clk.value() << 1) | self.dt.value()
        now = time.ticks_ms()

        if state != self.last_state and time.ticks_diff(now, self.last_time) > 5:
            self.last_time = now
            transition = (self.last_state << 2) | state
            self.last_state = state

            # Reversed directions to match intended CW = increase
            if transition in (0b0001, 0b0111, 0b1110, 0b1000):
                return -1  # Originally CW, now interpreted as decrease
            elif transition in (0b0010, 0b0100, 0b1101, 0b1011):
                return 1   # Originally CCW, now interpreted as increase

        return 0

    def get_button_press(self):
        if self.sw.value() == 0:
            time.sleep_ms(50)
            if self.sw.value() == 0:
                while self.sw.value() == 0:
                    pass
                return True
        return False

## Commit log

2025-07-04 Add files via upload
    [ 07 / 04 / 2025 ]
    PROTOTYPE BUILD
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2025-07-04 HARDWARE LIST / BOM
2025-07-04 Rename hardware.pdf to BILL OF MATERIALS.pdf
2025-07-04 HARDWARE LIST / BILL OF MATERIALS
2025-07-04 Rename BILL OF MATERIALS.pdf to BOM.pdf
2025-07-04 Rename BOM.pdf to bill of materials.pdf
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2025-07-06 upload case design [WIP]
    [sequencer_case_BACK_v2.2.stl, sequencer_case_FRONT_v2.1.stl, sequencer_case_INSERT_v1.0.stl]
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2025-07-07 Rename hardware/sequencer_case_BACK_v2.2.stl to hardware/case design/sequencer_case_BACK_v2.2.stl
    [sequencer_case_BACK_v2.2.stl]
2025-07-07 Rename hardware/sequencer_case_FRONT_v2.1.stl to hardware/case design/sequencer_case_FRONT_v2.1.stl
    [sequencer_case_FRONT_v2.1.stl]
2025-07-07 Rename hardware/sequencer_case_INSERT_v1.0.stl to hardware/case design/sequencer_case_INSERT_v1.0.stl
    [sequencer_case_INSERT_v1.0.stl]
2025-07-07 Rename hardware/PORTABLE AUDIO TOOL - WIRING DIAGRAM.pdf to hardware/diagrams/PORTABLE AUDIO TOOL - WIRING DIAGRAM.pdf
2025-07-07 Rename hardware/PERIPHERALS & GPIO - WIRING DIAGRAM.pdf to hardware/wiring diagrams/PERIPHERALS & GPIO - WIRING DIAGRAM.pdf
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2025-07-23 Rename hardware/case design/sequencer_case_BACK_v2.2.stl to hardware/case design/STL/sequencer_case_BACK_v2.2.stl
    [sequencer_case_BACK_v2.2.stl]
2025-07-23 Rename hardware/case design/sequencer_case_FRONT_v2.1.stl to hardware/case design/STL/sequencer_case_FRONT_v2.1.stl
    [sequencer_case_FRONT_v2.1.stl]
2025-07-23 Rename hardware/case design/sequencer_case_INSERT_v1.0.stl to hardware/case design/STL/sequencer_case_INSERT_v1.0.stl
    [sequencer_case_INSERT_v1.0.stl]
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2025-09-03 Delete hardware/wiring diagrams/AUDIO SIGNALS - WIRING DIAGRAM.pdf
    UPDATING TO REV B
2025-09-10 Update and rename hardware/AUDIOBOARD - BUFFERED INJECTION MIXER-NPTH.drl to hardware/pcb layout/BUFFERED INJECTION MIXER-NPTH.drl
    [BUFFERED INJECTION MIXER-NPTH.drl]
2025-09-10 Update and rename hardware/AUDIOBOARD - BUFFERED INJECTION MIXER-PTH.drl to hardware/pcb layout/AUDIOBOARD - BUFFERED INJECTION MIXER-PTH.drl
    [AUDIOBOARD - BUFFERED INJECTION MIXER-PTH.drl]
2025-09-10 Update and rename AUDIOBOARD - BUFFERED INJECTION MIXER-PTH.drl to BUFFERED INJECTION MIXER-PTH.drl
    [BUFFERED INJECTION MIXER-PTH.drl]
2025-09-10 Update and rename hardware/pcb layout/BUFFERED INJECTION MIXER-NPTH.drl to hardware/pcb layout/DRL/BUFFERED INJECTION MIXER-NPTH.drl
    [BUFFERED INJECTION MIXER-NPTH.drl]
2025-09-10 Update and rename hardware/pcb layout/BUFFERED INJECTION MIXER-PTH.drl to hardware/pcb layout/DRL/BUFFERED INJECTION MIXER-PTH.drl
    [BUFFERED INJECTION MIXER-PTH.drl]
2025-09-10 Update and rename hardware/pcb layout/AUDIOBOARD - BUFFERED INJECTION MIXER-B_Cu.gbr to hardware/pcb layout/GBR/AUDIOBOARD - BUFFERED INJECTION MIXER-B_Cu.gbr
    [AUDIOBOARD - BUFFERED INJECTION MIXER-B_Cu.gbr]
2025-09-10 Update and rename hardware/pcb layout/AUDIOBOARD - BUFFERED INJECTION MIXER-B_Mask.gbr to hardware/pcb layout/GBR/AUDIOBOARD - BUFFERED INJECTION MIXER-B_Mask.gbr
    [AUDIOBOARD - BUFFERED INJECTION MIXER-B_Mask.gbr]
2025-09-10 Update and rename hardware/pcb layout/AUDIOBOARD - BUFFERED INJECTION MIXER-B_Paste.gbr to hardware/pcb layout/GBR/AUDIOBOARD - BUFFERED INJECTION MIXER-B_Paste.gbr
    [AUDIOBOARD - BUFFERED INJECTION MIXER-B_Paste.gbr]
2025-09-10 Update and rename hardware/pcb layout/AUDIOBOARD - BUFFERED INJECTION MIXER-B_Silkscreen.gbr to hardware/pcb layout/GBR/AUDIOBOARD - BUFFERED INJECTION MIXER-B_Silkscreen.gbr
    [AUDIOBOARD - BUFFERED INJECTION MIXER-B_Silkscreen.gbr]
2025-09-10 Update and rename hardware/pcb layout/AUDIOBOARD - BUFFERED INJECTION MIXER-Edge_Cuts.gbr to hardware/pcb layout/GBR/AUDIOBOARD - BUFFERED INJECTION MIXER-Edge_Cuts.gbr
    [AUDIOBOARD - BUFFERED INJECTION MIXER-Edge_Cuts.gbr]
2025-09-10 Update and rename hardware/pcb layout/AUDIOBOARD - BUFFERED INJECTION MIXER-F_Cu.gbr to hardware/pcb layout/GBR/AUDIOBOARD - BUFFERED INJECTION MIXER-F_Cu.gbr
    [AUDIOBOARD - BUFFERED INJECTION MIXER-F_Cu.gbr]
2025-09-10 Update and rename hardware/pcb layout/AUDIOBOARD - BUFFERED INJECTION MIXER-F_Mask.gbr to hardware/pcb layout/GBR/AUDIOBOARD - BUFFERED INJECTION MIXER-F_Mask.gbr
    [AUDIOBOARD - BUFFERED INJECTION MIXER-F_Mask.gbr]
2025-09-10 Update and rename hardware/pcb layout/AUDIOBOARD - BUFFERED INJECTION MIXER-F_Paste.gbr to hardware/pcb layout/GBR/AUDIOBOARD - BUFFERED INJECTION MIXER-F_Paste.gbr
    [AUDIOBOARD - BUFFERED INJECTION MIXER-F_Paste.gbr]
2025-09-10 Update and rename hardware/pcb layout/AUDIOBOARD - BUFFERED INJECTION MIXER-F_Silkscreen.gbr to hardware/pcb layout/GBR/AUDIOBOARD - BUFFERED INJECTION MIXER-F_Silkscreen.gbr
    [AUDIOBOARD - BUFFERED INJECTION MIXER-F_Silkscreen.gbr]
2025-09-10 Update and rename hardware/pcb layout/AUDIOBOARD - BUFFERED INJECTION MIXER-job.gbrjob to hardware/pcb layout/GBR/AUDIOBOARD - BUFFERED INJECTION MIXER-job.gbrjob
    [AUDIOBOARD - BUFFERED INJECTION MIXER-job.gbrjob]
